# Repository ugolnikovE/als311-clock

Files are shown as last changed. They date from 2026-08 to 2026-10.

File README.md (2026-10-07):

# als311-clock

A clock built around the Soviet ALS311 LED display — I made it as a gift for my wife.
It runs on an ATmega328P with firmware written in C. The firmware uses an asynchronous
model: all drivers and HAL functions operate without blocking the main loop.

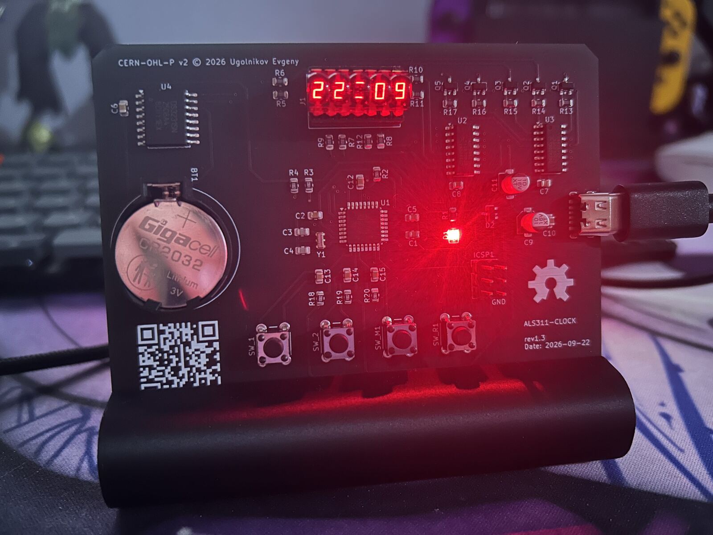
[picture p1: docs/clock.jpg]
Assembled clock


Prebuilt firmware and fabrication files (Gerbers, BOM) are on the
[Releases](https://github.com/ugolnikovE/als311-clock/releases) page.

## Components

| Component | Qty |
| --- | --- |
| ATmega328P microcontroller | 1 |
| DS3231M real-time clock | 1 |
| 74HC595 shift register | 2 |
| ALS311 7-segment display | 1 |
| MMBT2222A transistor | 5 |
| BAT54C Schottky diode | 1 |
| LED | 1 |
| 16 MHz crystal | 1 |
| USB-C connector (power) | 1 |
| CR2032 battery + holder | 1 |
| Tactile push button | 4 |
| ICSP programming header | 1 |
| Resistors (1 k / 4.7 k / 10 k) | 20 |
| Capacitors (0.1 µF / 22 pF / 10 µF) | 15 |

> [!WARNING]
> Double-check resistor values **and units** when ordering parts and before soldering.
> 4.7 Ω and 4.7 kΩ look almost the same in a shop listing, and the board will not
> work with the wrong one.

## Schematic

Full multi-sheet schematic: [docs/schematic.pdf](docs/schematic.pdf).
KiCad sources are in [hardware](hardware).

## PCB

KiCad layout: [hardware/hardware.kicad_pcb](hardware/hardware.kicad_pcb).

## Enclosure

A stand that holds the board at an angle. FreeCAD source in
[hardware/enclosure](hardware/enclosure).

## Firmware

### Requirements

- avr-gcc
- avrdude
- Make

For working with the hardware sources: KiCad 9, and FreeCAD (for the stand, optional).

### Build

```bash
cd firmware
make
```

### Flash

The board has no bootloader. It is programmed over the ICSP header (USBasp by default).

```bash
cd firmware
make upload
```

### First flash: fuses

A new ATmega328P runs from its internal RC oscillator at 1 MHz. The firmware expects
an external 16 MHz crystal, so on a new chip set the fuses once before the first upload:

```bash
avrdude -c usbasp -p m328p -B 32 \
    -U lfuse:w:0xFF:m -U hfuse:w:0xD9:m -U efuse:w:0xFD:m
```

| Fuse | Value | Meaning |
| --- | --- | --- |
| lfuse | `0xFF` | external crystal 8–16 MHz, CKDIV8 off |
| hfuse | `0xD9` | no bootloader (BOOTRST off), SPIEN on |
| efuse | `0xFD` | brown-out detection at 2.7 V |

Notes:

- `-B 32` slows the ISP clock down. A 1 MHz chip will not answer at the default speed.
  Once the fuses are set, `make upload` works at normal speed.
- Solder the crystal and its 22 pF capacitors **before** writing the fuses. With these
  fuses the chip will not start without a working crystal, so ISP can't reach it either.

## Contributing

Ideas, bug reports and any contributions are welcome — feel free to open an issue
or a pull request.

## License

- **Firmware** (`/firmware`) — MIT, see [LICENSE](LICENSE).
- **Hardware** (`/hardware`) — schematics, PCB and enclosure — CERN-OHL-P v2,
  see [LICENSE-HARDWARE](LICENSE-HARDWARE) and [hardware/NOTICE](hardware/NOTICE).

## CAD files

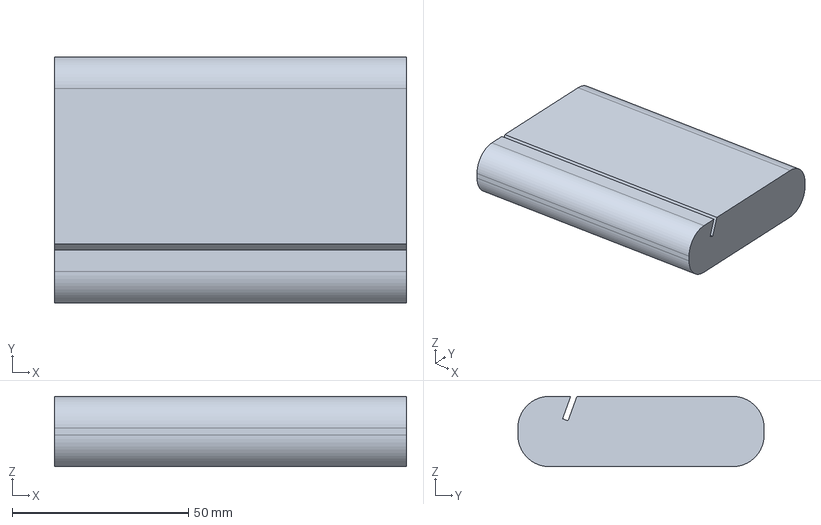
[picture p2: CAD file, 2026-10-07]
hardware/enclosure/SimpleEnclosure.FCStd
100.0 x 70.0 x 20.0 mm

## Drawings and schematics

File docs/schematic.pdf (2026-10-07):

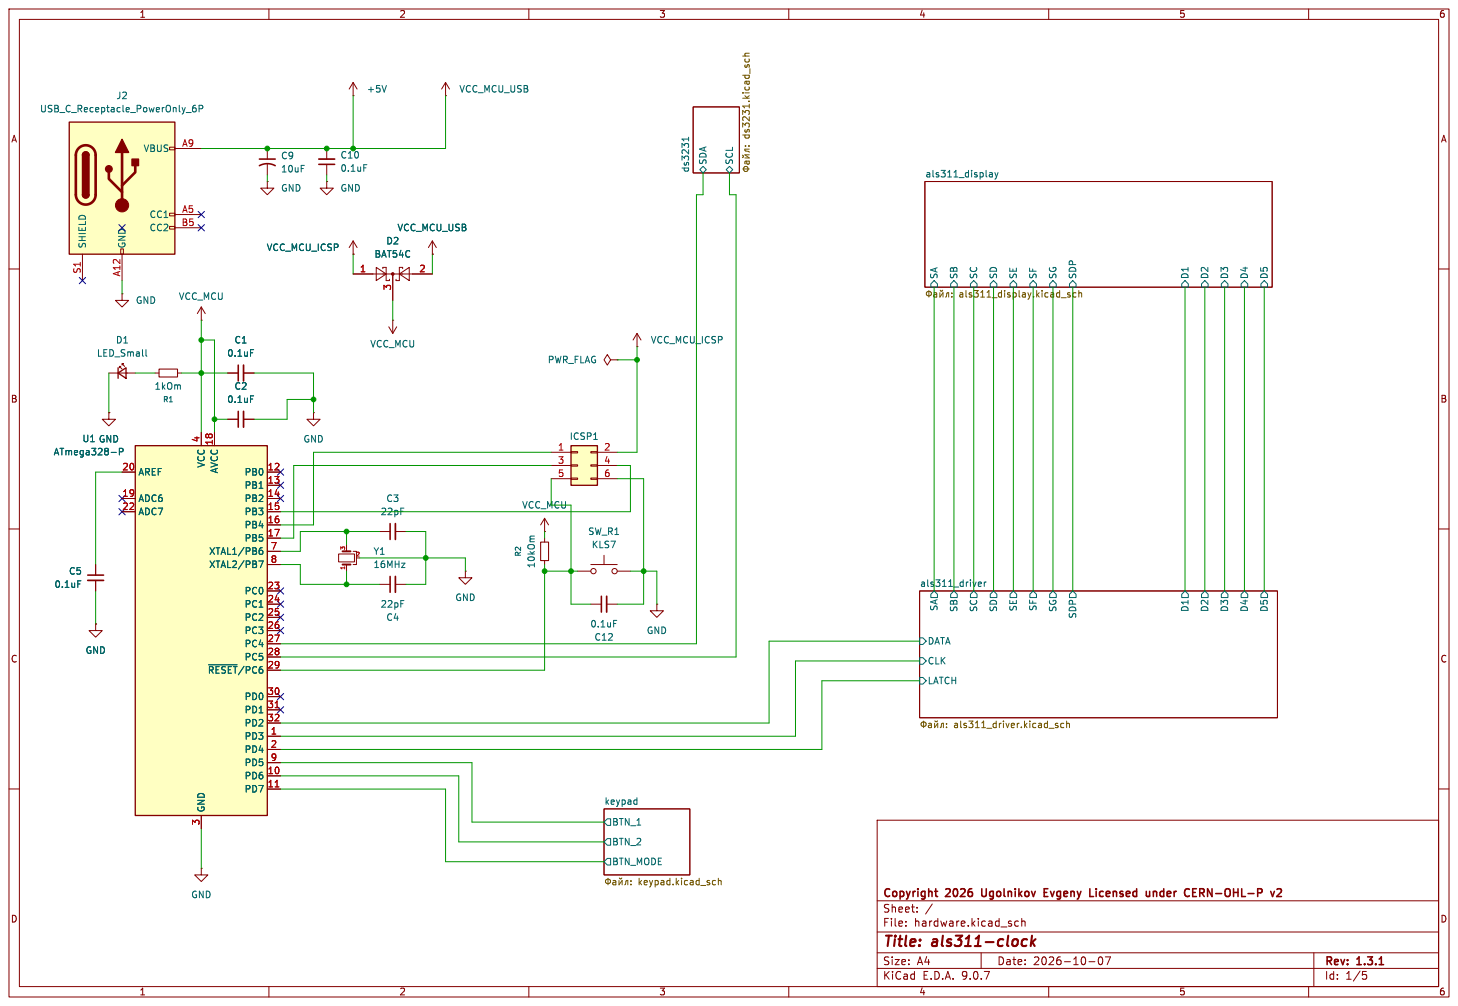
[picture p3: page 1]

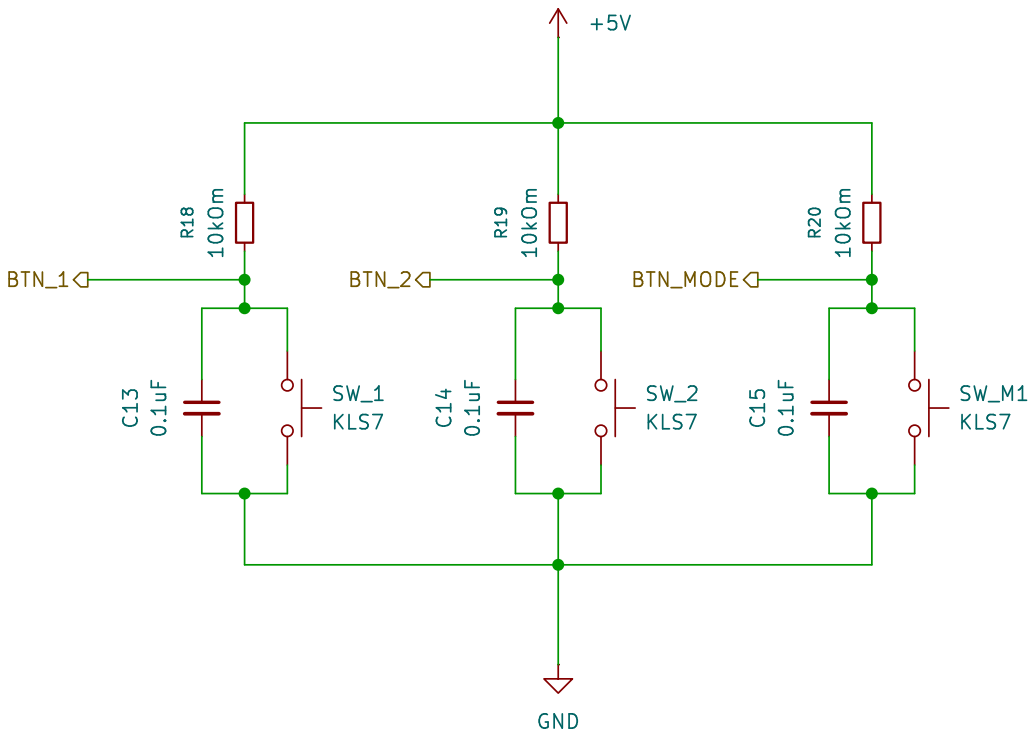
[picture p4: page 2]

File: keypad.kicad_sch Sheet: /keypad/
Id: 2/5 Title: als311-clock

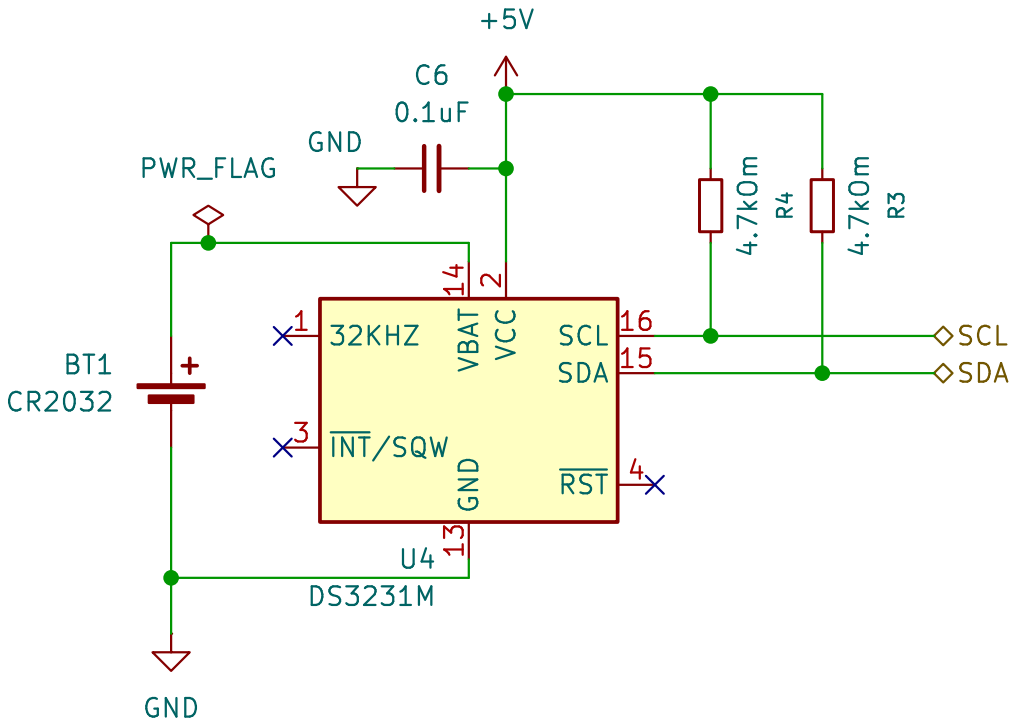
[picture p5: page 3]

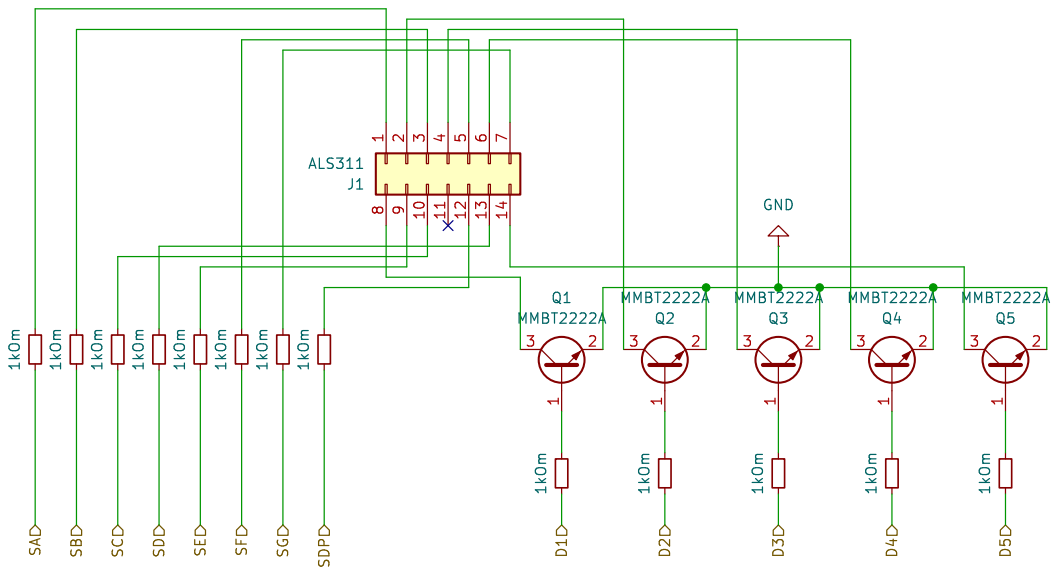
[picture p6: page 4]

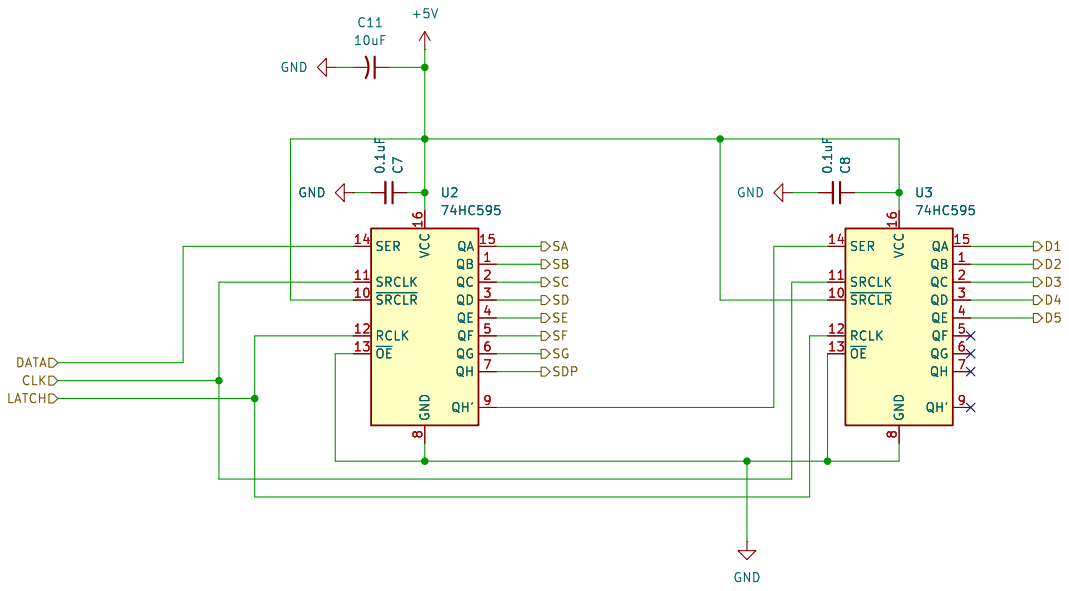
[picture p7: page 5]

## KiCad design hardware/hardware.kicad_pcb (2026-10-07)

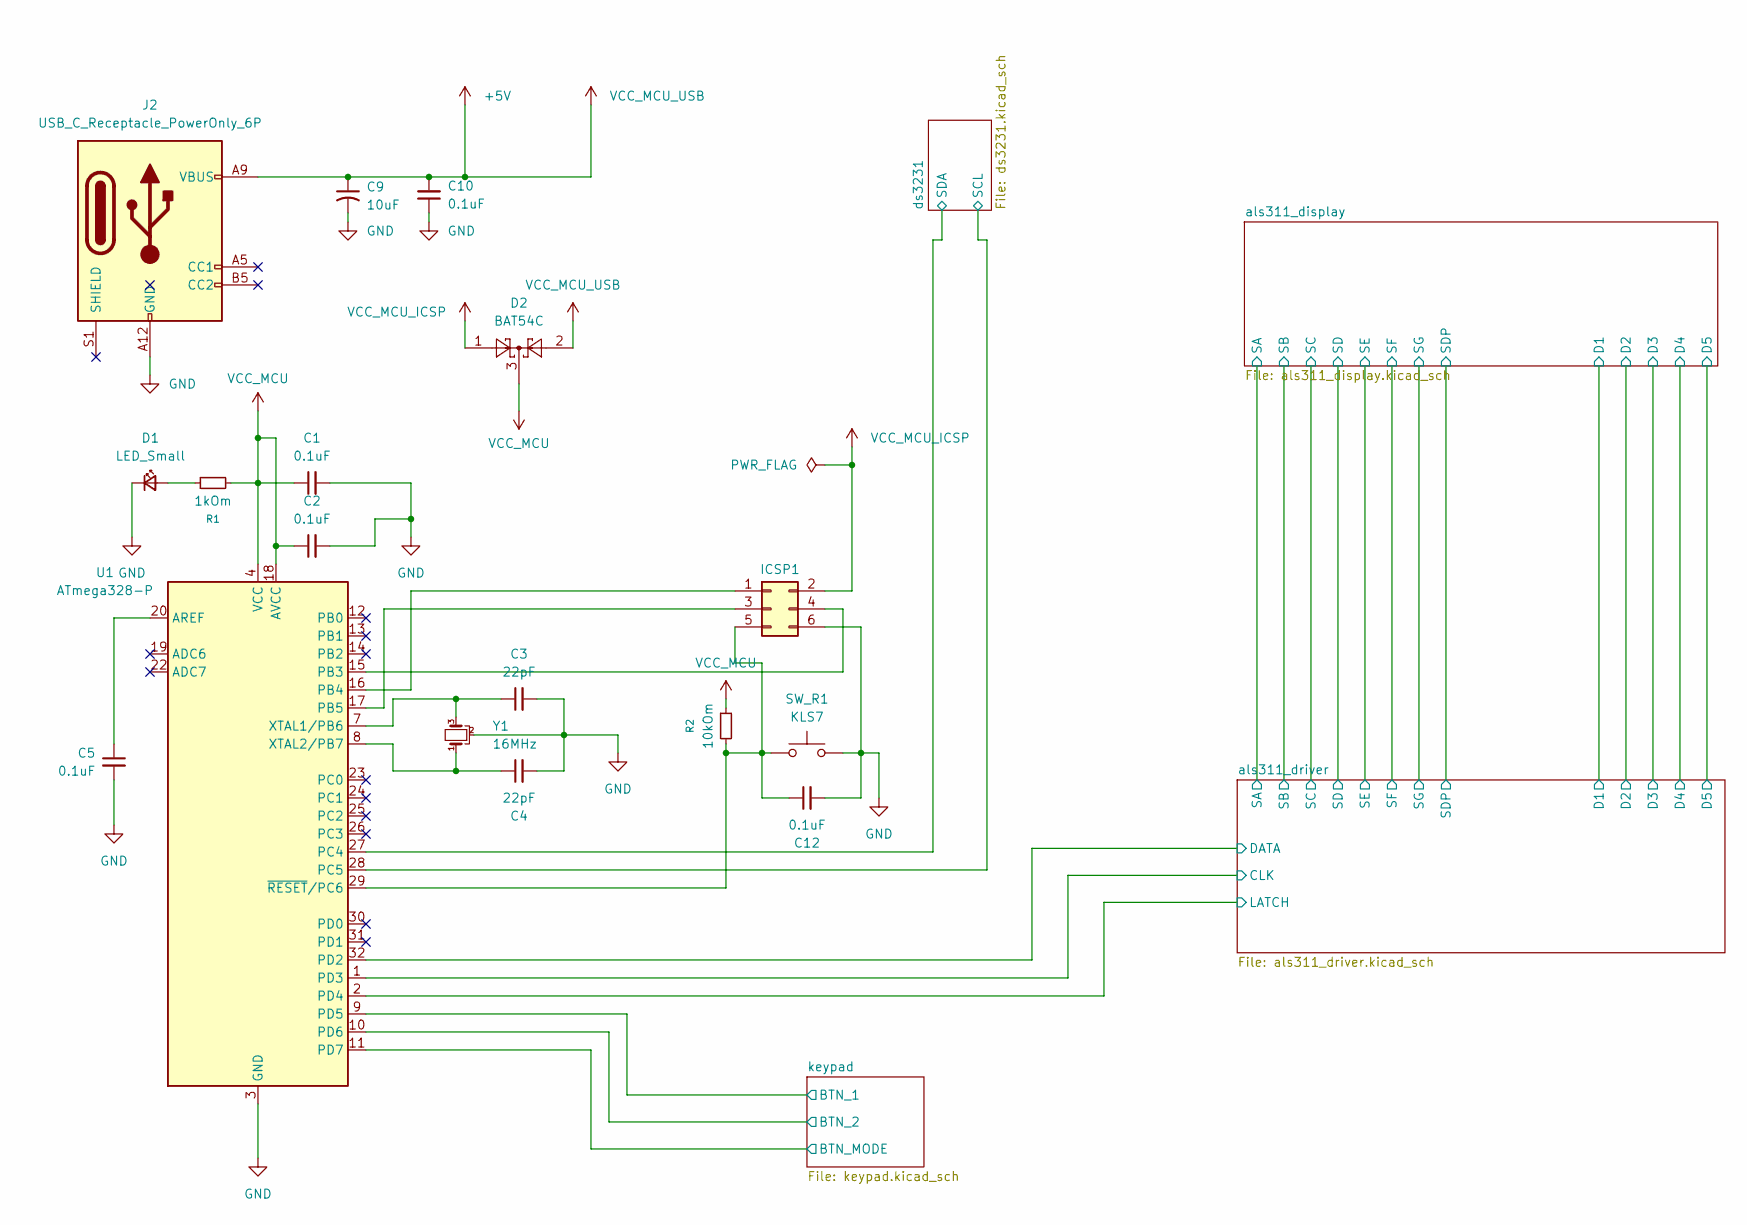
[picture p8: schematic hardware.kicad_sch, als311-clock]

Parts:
C1, C2, C5, C10, C12: 0.1uF; C_0805_2012Metric
C3, C4: 22pF; C_0805_2012Metric
C9: 10uF; C_Elec_4x5.4
D1: LED_Small; LED_0805_2012Metric
D2: BAT54C; SOT-23
ICSP1: ICSP; PinHeader_2x03_P2.54mm_Vertical
J2: USB_C_Receptacle_PowerOnly_6P; USB_C_Receptacle_HRO_TYPE-C-31-M-17
R1: 1kOm; R_0805_2012Metric
R2: 10kOm; R_0805_2012Metric
SW_R1: KLS7; SW_PUSH_6mm
U1: ATmega328-P; TQFP-32_7x7mm_P0.8mm
Y1: 16MHz; Resonator_SMD_CTSC_1.3mmx3.2mm

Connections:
+5V: C9.1, C10.2, D2.2, J2.A9 (VBUS), J2.B9 (VBUS); also elsewhere on the board
/als311_driver/CLK: U1.1 (PD3); also elsewhere on the board
/als311_driver/DATA: U1.32 (PD2); also elsewhere on the board
/als311_driver/LATCH: U1.2 (PD4); also elsewhere on the board
/ds3231/SCL: U1.28 (PC5); also elsewhere on the board
/ds3231/SDA: U1.27 (PC4); also elsewhere on the board
/keypad/BTN_1: U1.9 (PD5); also elsewhere on the board
/keypad/BTN_2: U1.10 (PD6); also elsewhere on the board
/keypad/BTN_MODE: U1.11 (PD7); also elsewhere on the board
GND: C1.2, C2.2, C3.2, C4.2, C5.2, C9.2, C10.1, C12.2, D1.1 (K), ICSP1.6, J2.A12 (GND), J2.B12 (GND), SW_R1.2, U1.3 (GND), U1.5 (GND), U1.21 (GND), Y1.2; also elsewhere on the board
unnamed: D1.2 (A), R1.1
unnamed: ICSP1.1, U1.16 (PB4)
unnamed: ICSP1.3, U1.17 (PB5)
unnamed: ICSP1.4, U1.15 (PB3)
unnamed: C12.1, ICSP1.5, R2.2, SW_R1.1, U1.29 (~RESET/PC6)
unnamed: C5.1, U1.20 (AREF)
unnamed: C3.1, U1.7 (XTAL1/PB6), Y1.3
unnamed: C4.1, U1.8 (XTAL2/PB7), Y1.1
VCC_MCU: C1.1, C2.1, D2.3, R1.2, R2.1, U1.4 (VCC), U1.6 (VCC), U1.18 (AVCC)
VCC_MCU_ICSP: D2.1, ICSP1.2

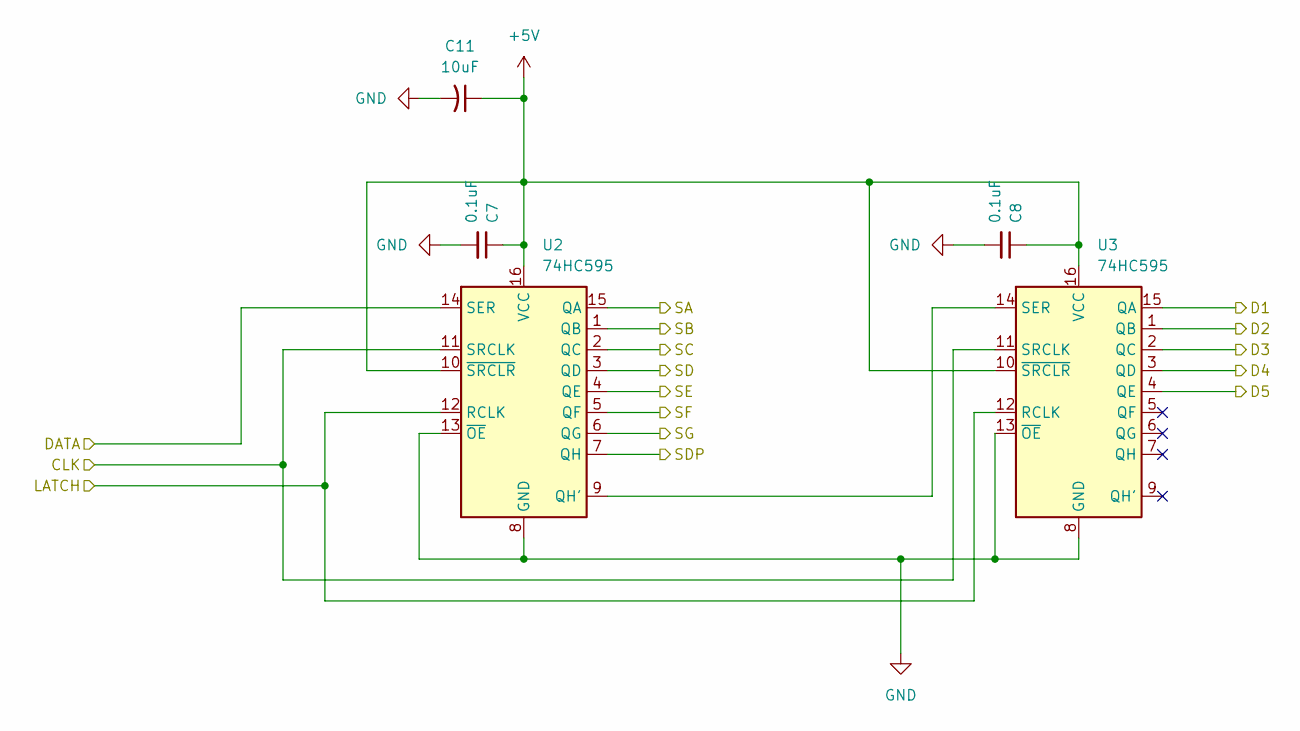
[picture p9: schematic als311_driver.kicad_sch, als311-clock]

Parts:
C7, C8: 0.1uF; C_0805_2012Metric
C11: 10uF; C_Elec_4x5.4
U2, U3: 74HC595; SOIC-16_3.9x9.9mm_P1.27mm

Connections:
+5V: C7.1, C8.1, C11.1, U2.10 (~SRCLR), U2.16 (VCC), U3.10 (~SRCLR), U3.16 (VCC); also elsewhere on the board
/als311_display/D1: U3.15 (QA); also elsewhere on the board
/als311_display/D2: U3.1 (QB); also elsewhere on the board
/als311_display/D3: U3.2 (QC); also elsewhere on the board
/als311_display/D4: U3.3 (QD); also elsewhere on the board
/als311_display/D5: U3.4 (QE); also elsewhere on the board
/als311_display/SA: U2.15 (QA); also elsewhere on the board
/als311_display/SB: U2.1 (QB); also elsewhere on the board
/als311_display/SC: U2.2 (QC); also elsewhere on the board
/als311_display/SD: U2.3 (QD); also elsewhere on the board
/als311_display/SDP: U2.7 (QH); also elsewhere on the board
/als311_display/SE: U2.4 (QE); also elsewhere on the board
/als311_display/SF: U2.5 (QF); also elsewhere on the board
/als311_display/SG: U2.6 (QG); also elsewhere on the board
/als311_driver/CLK: U2.11 (SRCLK), U3.11 (SRCLK); also elsewhere on the board
/als311_driver/DATA: U2.14 (SER); also elsewhere on the board
/als311_driver/LATCH: U2.12 (RCLK), U3.12 (RCLK); also elsewhere on the board
GND: C7.2, C8.2, C11.2, U2.8 (GND), U2.13 (~OE), U3.8 (GND), U3.13 (~OE); also elsewhere on the board
unnamed: U2.9 (QH'), U3.14 (SER)

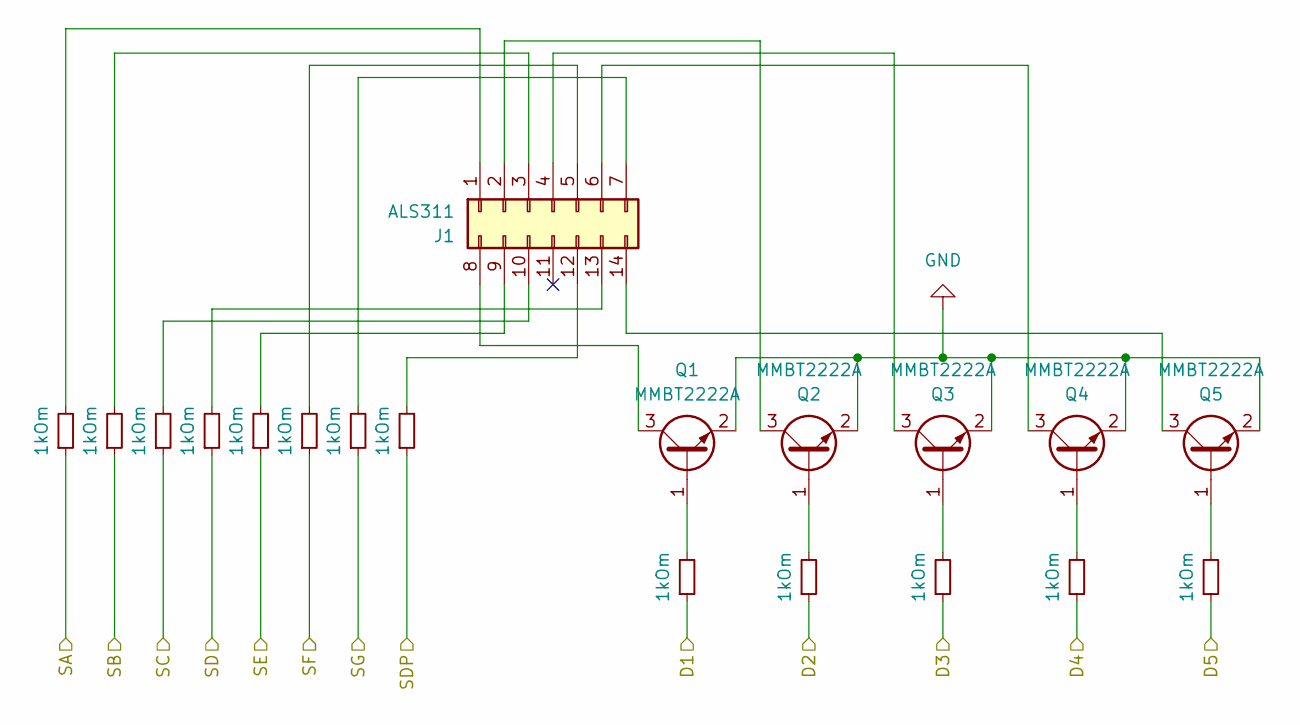
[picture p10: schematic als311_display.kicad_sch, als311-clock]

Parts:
J1: ALS311; DIP-14_W7.62mm_Socket
Q1, Q2, Q3, Q4, Q5: MMBT2222A; SOT-23
R5, R6, R7, R8, R9, R10, R11, R12, R13, R14, R15, R16, R17: 1kOm; R_0805_2012Metric

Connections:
/als311_display/D1: R13.1; also elsewhere on the board
/als311_display/D2: R14.1; also elsewhere on the board
/als311_display/D3: R15.1; also elsewhere on the board
/als311_display/D4: R16.1; also elsewhere on the board
/als311_display/D5: R17.1; also elsewhere on the board
/als311_display/SA: R5.1; also elsewhere on the board
/als311_display/SB: R6.1; also elsewhere on the board
/als311_display/SC: R7.1; also elsewhere on the board
/als311_display/SD: R8.1; also elsewhere on the board
/als311_display/SDP: R12.1; also elsewhere on the board
/als311_display/SE: R9.1; also elsewhere on the board
/als311_display/SF: R10.1; also elsewhere on the board
/als311_display/SG: R11.1; also elsewhere on the board
GND: Q1.2 (E), Q2.2 (E), Q3.2 (E), Q4.2 (E), Q5.2 (E); also elsewhere on the board
unnamed: J1.1, R5.2
unnamed: J1.2, Q2.3 (C)
unnamed: J1.3, R6.2
unnamed: J1.4, Q3.3 (C)
unnamed: J1.5, R10.2
unnamed: J1.6, Q4.3 (C)
unnamed: J1.7, R11.2
unnamed: J1.8, Q1.3 (C)
unnamed: J1.9, R9.2
unnamed: J1.10, R7.2
unnamed: J1.12, R12.2
unnamed: J1.13, R8.2
unnamed: J1.14, Q5.3 (C)
unnamed: Q1.1 (B), R13.2
unnamed: Q2.1 (B), R14.2
unnamed: Q3.1 (B), R15.2
unnamed: Q4.1 (B), R16.2
unnamed: Q5.1 (B), R17.2

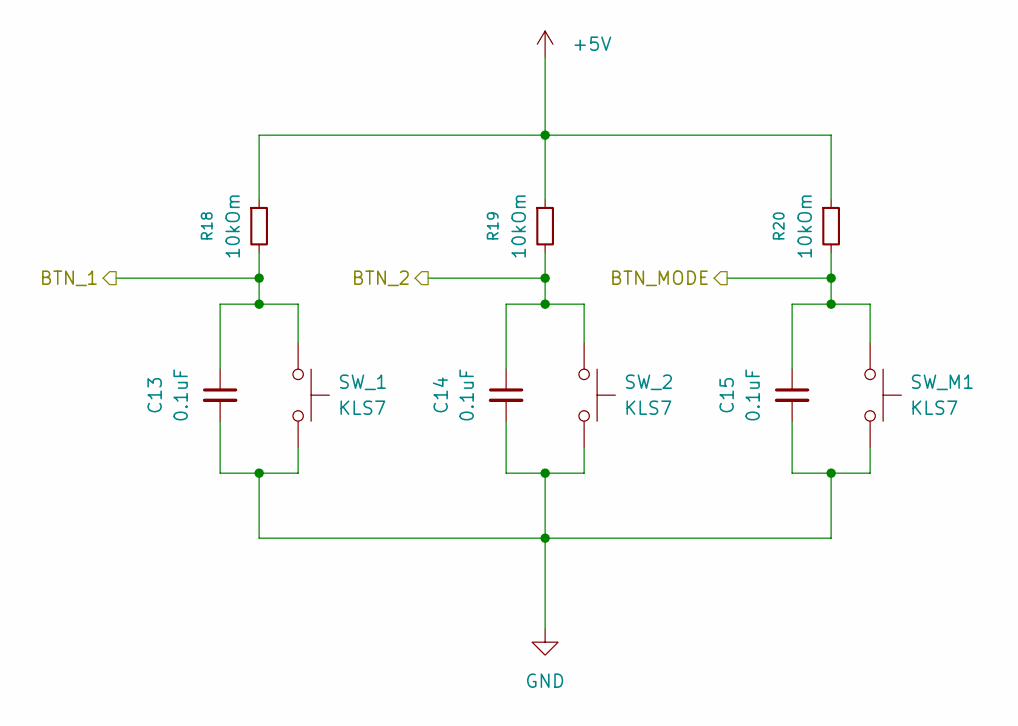
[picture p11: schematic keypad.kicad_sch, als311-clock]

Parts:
C13, C14, C15: 0.1uF; C_0805_2012Metric
R18, R19, R20: 10kOm; R_0805_2012Metric
SW_1, SW_2: KLS7; SW_PUSH_6mm
SW_M1: KLS7; SW_PUSH_6mm

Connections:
+5V: R18.1, R19.1, R20.1; also elsewhere on the board
/keypad/BTN_1: C13.1, R18.2, SW_1.1; also elsewhere on the board
/keypad/BTN_2: C14.1, R19.2, SW_2.1; also elsewhere on the board
/keypad/BTN_MODE: C15.1, R20.2, SW_M1.1; also elsewhere on the board
GND: C13.2, C14.2, C15.2, SW_1.2, SW_2.2, SW_M1.2; also elsewhere on the board

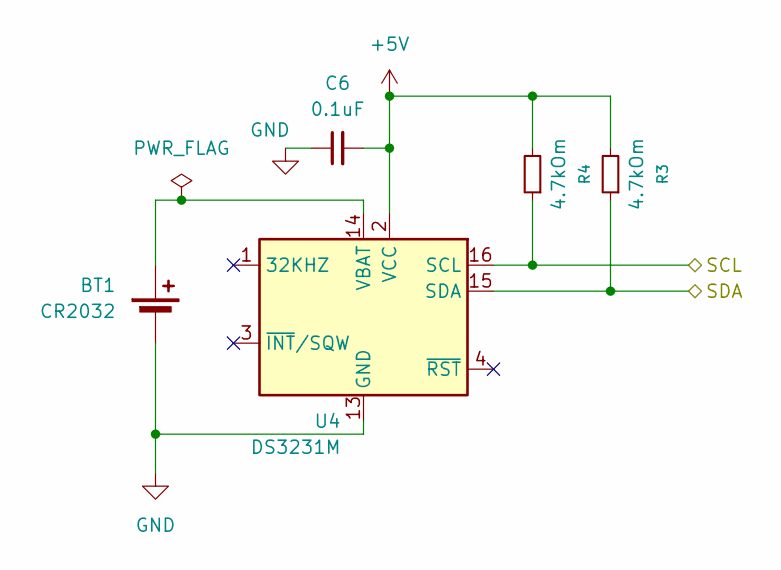
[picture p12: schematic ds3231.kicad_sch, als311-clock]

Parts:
BT1: CR2032; BatteryHolder_MYOUNG_BS-07-A1BJ001_CR2032
C6: 0.1uF; C_0805_2012Metric
R3, R4: 4.7kOm; R_0805_2012Metric
U4: DS3231M; SOIC-16W_7.5x10.3mm_P1.27mm

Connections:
+5V: C6.2, R3.2, R4.2, U4.2 (VCC); also elsewhere on the board
/ds3231/SCL: R4.1, U4.16 (SCL); also elsewhere on the board
/ds3231/SDA: R3.1, U4.15 (SDA); also elsewhere on the board
GND: BT1.2 (-), C6.1, U4.5 (GND), U4.6 (GND), U4.7 (GND), U4.8 (GND), U4.9 (GND), U4.10 (GND), U4.11 (GND), U4.12 (GND), U4.13 (GND); also elsewhere on the board
unnamed: BT1.1 (+), U4.14 (VBAT)

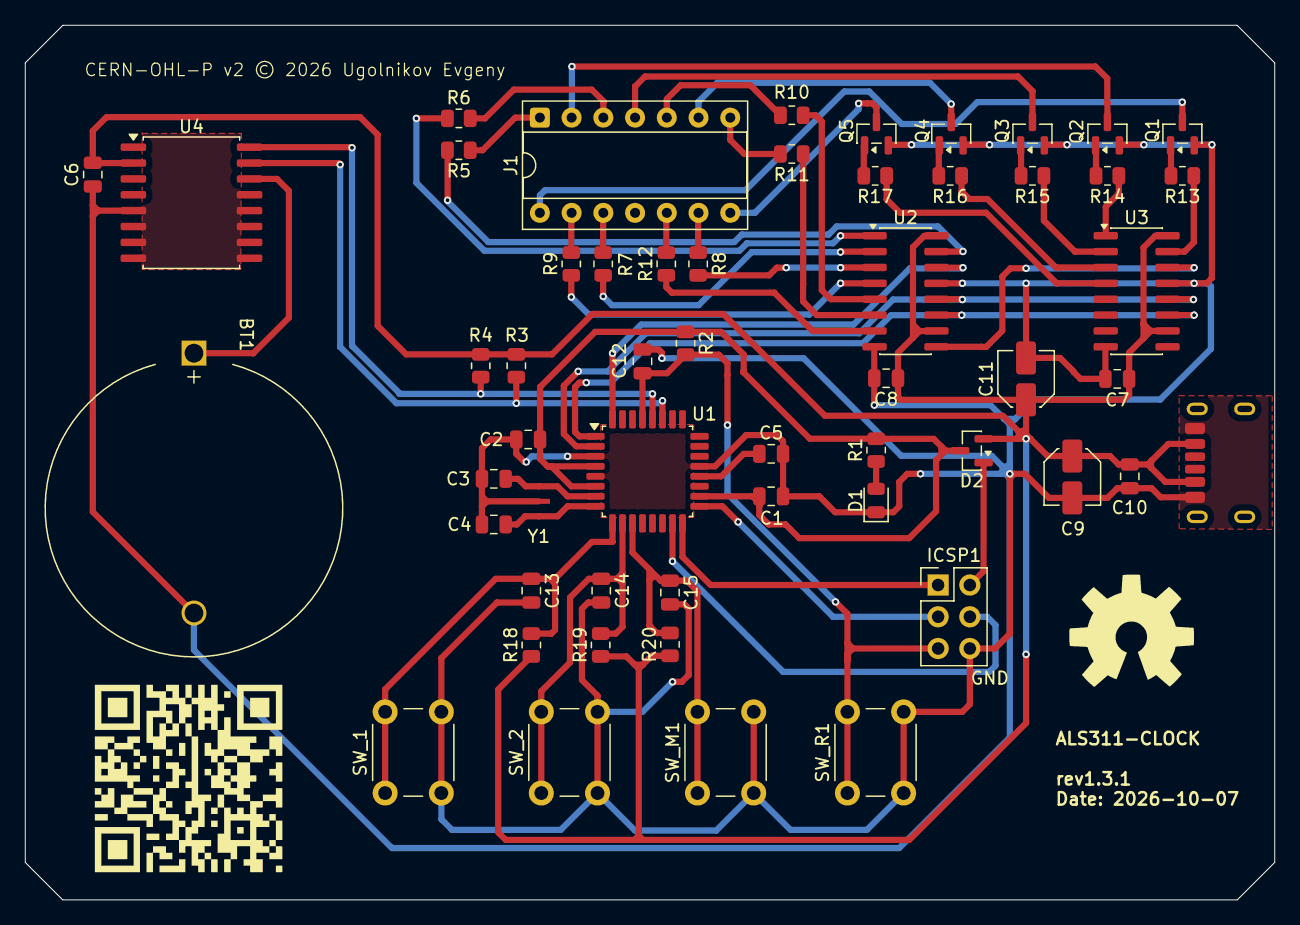
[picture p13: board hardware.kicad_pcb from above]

Board: 2 copper layers, 100.0 x 70.0 mm, 55 parts (0 on the bottom side), 53 nets.

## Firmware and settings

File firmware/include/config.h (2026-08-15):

#ifndef CONFIG_H
#define CONFIG_H

#include <avr/io.h>

// MCU Clock
#define F_CPU 16000000UL

// Shift Register
#define SR_DS_PORT    PORTD
#define SR_DS_PIN     PD2
#define SR_CLK_PORT   PORTD
#define SR_CLK_PIN    PD3
#define SR_LATCH_PORT PORTD
#define SR_LATCH_PIN  PD4

// I2C
#define I2C_FREQUENCY 400000UL

// Buttons
#define BTN_COUNT  3
#define BTN_1_PORT PORTD
#define BTN_1_PIN  PD5
#define BTN_2_PORT PORTD
#define BTN_2_PIN  PD6
#define BTN_3_PORT PORTD
#define BTN_3_PIN  PD7

// UART
#define BAUD 9600

#endif // CONFIG_H

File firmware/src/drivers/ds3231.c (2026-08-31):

#include <avr/common.h>
#include <avr/interrupt.h>
#include <stddef.h>
#include <stdint.h>
#include <string.h>

#include "drivers/ds3231.h"
#include "hal/i2c.h"
#include "hal/systimer.h"

#define DS3231_I2C_ADDR     0x68
#define DS3231_I2C_TIME_REG 0x00
#define DS3231_I2C_TEMP_REG 0x11
#define DS3231_UPDATE_MS    10
#define DS3231_SYNC_MS      25

typedef enum {
        OP_READ,
        OP_WRITE
} ds3231_op_t;

static uint8_t buf[8];
static uint8_t sync_ctr = DS3231_SYNC_MS;
static ds3231_status_t st = DS3231_IDLE;
static ds3231_time_t b_tm;
static ds3231_op_t op;
static uint8_t pending_write = 0;
static ds3231_time_t pending_tm;

static inline uint8_t int_to_bcd(uint8_t n)
{
        return (n / 10 << 4) | (n % 10);
}

static inline uint8_t bcd_to_int(uint8_t n)
{
        return (n >> 4) * 10 + (n & 0x0F);
}

void ds3231_parse_buf()
{
        b_tm.seconds = bcd_to_int(buf[1] & 0x7F);
        b_tm.minutes = bcd_to_int(buf[2] & 0x7F);
        b_tm.hours   = bcd_to_int(buf[3] & 0x3F);
        b_tm.week    = bcd_to_int(buf[4] & 0x07);
        b_tm.date    = bcd_to_int(buf[5] & 0x3F);
        b_tm.month   = bcd_to_int(buf[6] & 0x1F);
        b_tm.year    = bcd_to_int(buf[7]);
}

static void ds3231_sync_time(void)
{
        if(!i2c_read_async(DS3231_I2C_ADDR, DS3231_I2C_TIME_REG, buf + 1, 7)) {
                st = DS3231_WORK;
                op = OP_READ;
        }
}

static void ds3231_start_write(void)
{
        buf[0] = 0x00;
        buf[1] = int_to_bcd(pending_tm.seconds);
        buf[2] = int_to_bcd(pending_tm.minutes);
        buf[3] = int_to_bcd(pending_tm.hours) & 0x3F;
        buf[4] = int_to_bcd(pending_tm.week);
        buf[5] = int_to_bcd(pending_tm.date);
        buf[6] = int_to_bcd(pending_tm.month);
        buf[7] = int_to_bcd(pending_tm.year);

        if (!i2c_write_async(DS3231_I2C_ADDR, buf, 8)) {
                st = DS3231_WORK;
                op = OP_WRITE;
        }
}


static void ds3231_update(void)
{
        i2c_status_t i2c_st = i2c_get_status();
        if (st == DS3231_WORK) {
                if (i2c_st == I2C_OK) {
                        if (op == OP_READ) {
                                if (!pending_write) ds3231_parse_buf();
                        } else {
                                pending_write = 0;
                        }
                        st = DS3231_OK;
                } else if (i2c_st == I2C_ERR) {
                        if (op == OP_WRITE) pending_write = 0;
                        st = DS3231_ERR;
                }
                return;
        }

        if (i2c_st == I2C_WORK) return;

        if (pending_write) {
                ds3231_start_write();
                return;
        }

        if (++sync_ctr >= DS3231_SYNC_MS) {
                ds3231_sync_time();
                sync_ctr = 0;
        }
}

void ds3231_init(void)
{
        systimer_register_callback(&ds3231_update, DS3231_UPDATE_MS);
}

uint8_t ds3231_set_time(const ds3231_time_t *tm)
{
        if (tm == NULL) return 1;

        uint8_t sreg = SREG;
        cli();

        pending_tm = *tm;
        pending_write = 1;
        b_tm = *tm;

        SREG = sreg;
        return 0;
}

void ds3231_get_time(ds3231_time_t *tm)
{
        uint8_t sreg = SREG;
        cli();

        *tm = b_tm;

        SREG = sreg;
}

ds3231_status_t ds3231_get_status(void)
{
        return st;
}

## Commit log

2026-02-14 feat: add Timer0 CTC setup
2026-02-16 refactor: extract timer to sys/timer module
2026-03-28 feat: add als311 display driver
2026-08-07 feat: add non-blocking i2c layer
2026-08-10 feat: ds3231 non-blocking driver, first iteration
2026-08-10 fix: preserve SREG in critical sections instead of forcing sei()
    [als311.c]
2026-08-11 fix: remove rtc_time_t argument from rtc_get_time()
    [ds3231.c]
2026-08-14 feat(ds3231): rework into async, snapshot-based driver
    [ds3231.c]
2026-08-15 feat: add button driver
2026-08-31 fix: button handler, state switcher
    [ds3231.c]
2026-09-21 chore: update gitignore for kicad
2026-09-21 feat: add kicad schematics and pcb layout
    [als311_display.kicad_sch, als311_driver.kicad_sch, ds3231.kicad_sch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]
2026-09-22 fix: set polygons type and usb-c silkscreen
    [als311_display.kicad_sch, als311_driver.kicad_sch, ds3231.kicad_sch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]
2026-10-07 feat: add simple enclosure
    [SimpleEnclosure.FCStd]
2026-10-07 refactor: led resistor replaced
    [als311_display.kicad_sch, als311_driver.kicad_sch, ds3231.kicad_sch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]
2026-10-07 docs: add readme, photo and schematic pdf
2026-11-12 feat: temperature display added

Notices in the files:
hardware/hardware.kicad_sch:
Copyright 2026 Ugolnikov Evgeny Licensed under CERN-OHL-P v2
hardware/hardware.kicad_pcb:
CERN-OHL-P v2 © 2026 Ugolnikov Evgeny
